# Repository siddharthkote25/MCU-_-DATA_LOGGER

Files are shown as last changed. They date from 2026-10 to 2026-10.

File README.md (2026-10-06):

# Mcu Data Logger

A compact, battery-backed data logger board built around the ATmega328P-AU. It has a real-time clock for timestamping and 2 Mbit of external I²C EEPROM for storage, and it breaks out I²C, UART, GPIO and ICSP headers for sensors and programming. Designed end-to-end in **KiCad 10**.

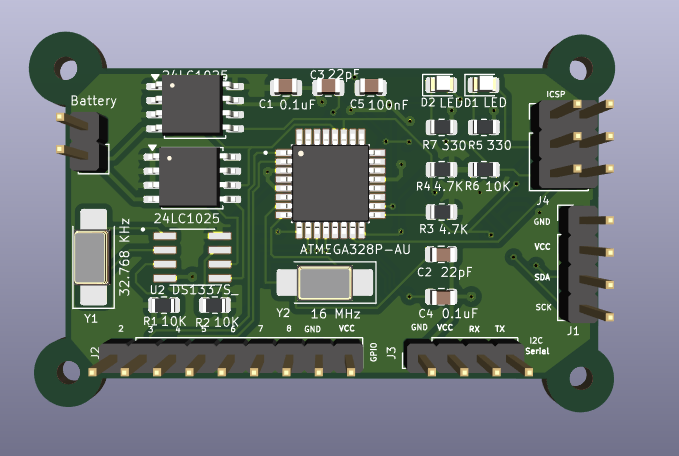
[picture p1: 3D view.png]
3D view


## Features

- **MCU:** ATmega328P-AU (TQFP-32) with a 16 MHz crystal and 22 pF load capacitors
- **Real-time clock:** DS1337 with a 32.768 kHz crystal, battery backup, and pull-ups on its SQW/INTA outputs
- **Storage:** 2 × 24LC1025 (1 Mbit each, 2 Mbit / 256 KB total) I²C EEPROMs, write-protect tied to GND
- **I²C bus:** 4.7 kΩ pull-ups on SDA/SCK, shared by the RTC and both EEPROMs
- **Indicators:** power LED and a status LED on SCK (D13)
- **Programming:** standard 2×3 ICSP header, with a 10 kΩ pull-up on RESET
- **Power:** battery input with decoupling on every IC, plus AREF filter capacitor
- **Mechanical:** four mounting holes, one in each corner

## Connectors

| Ref | Interface | Pins |
|-----|---|---|
| J1 | I²C | GND, VCC, SDA, SCK |
| J2 | GPIO | D2–D8, GND, VCC |
| J3 | Serial / UART | GND, VCC, RX, TX |
| J4 | ICSP | MISO, VCC, SCK, MOSI, RESET, GND |
| Battery | Power input | VCC, GND |

## Schematic

Hierarchical design, split into functional blocks:

- **MCU:** ATmega328P, crystal, reset circuit, LEDs, AREF filter
- **Real time clock:** DS1337, 32.768 kHz crystal, pull-ups, decoupling
- **EEPROM:** two 24LC1025 with address pins, write-protect and I²C pull-ups
- **Connectors:** I²C, UART, GPIO and ICSP (separate sub-sheet)
- **Mounting:** four mounting holes

**Sheet 1: MCU, RTC, EEPROM**

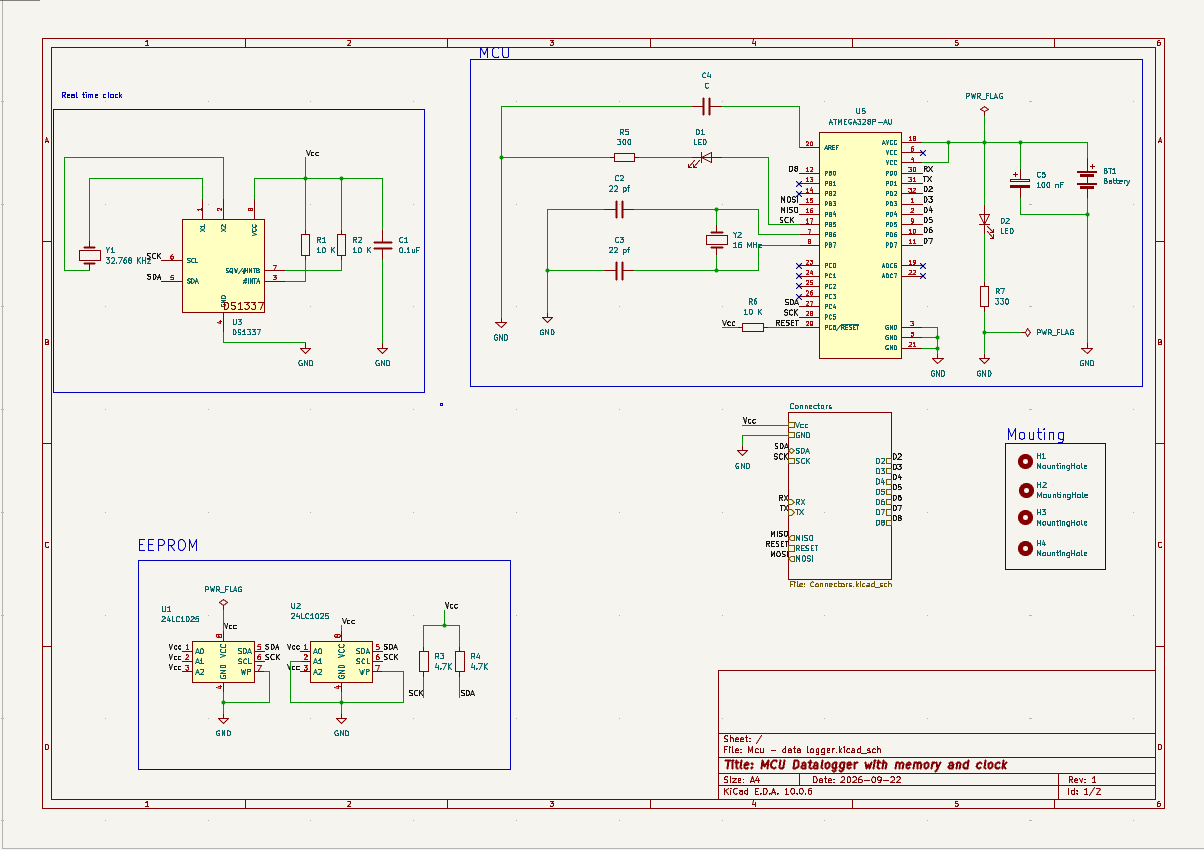
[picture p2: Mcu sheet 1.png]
Schematic sheet 1


**Sheet 2: Connectors**

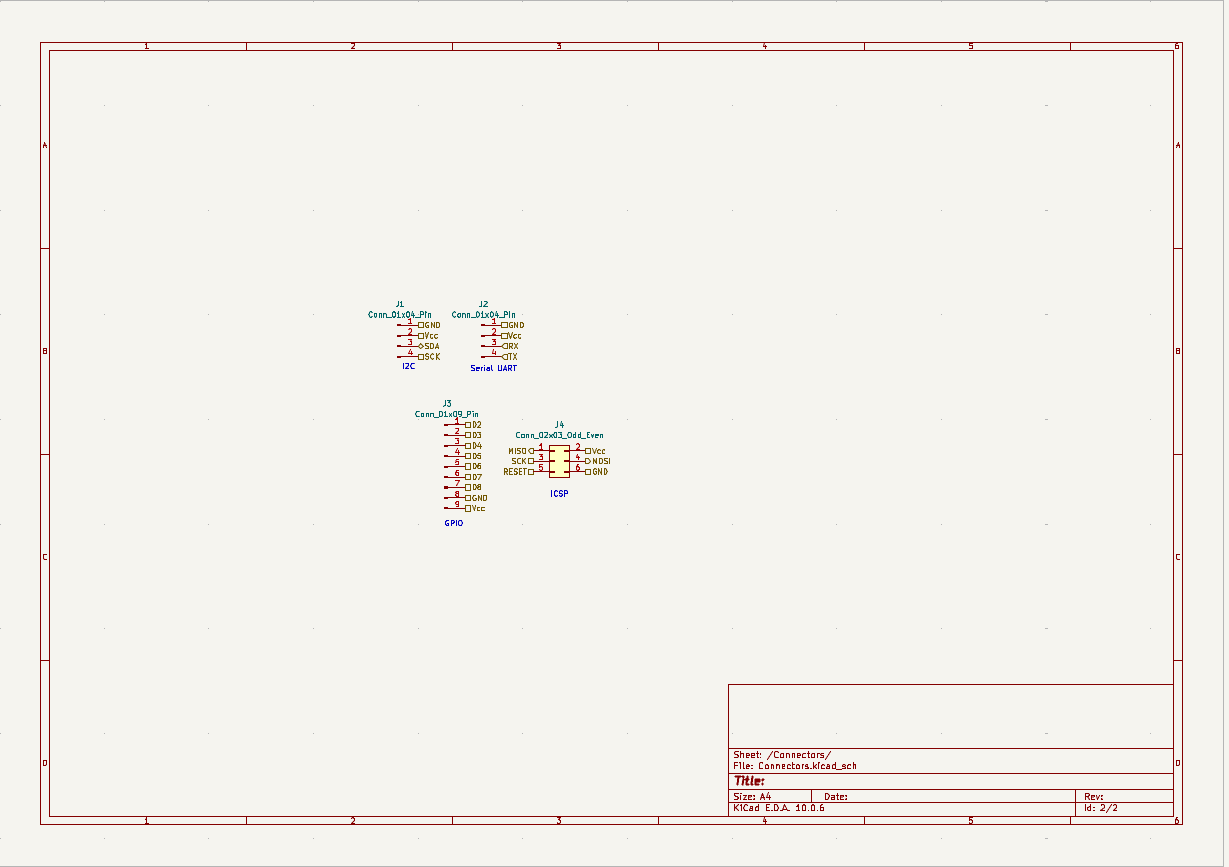
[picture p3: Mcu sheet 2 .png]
Schematic sheet 2


## PCB

- Layers: 2-layer
- Board size: [XX mm × XX mm]
- Components: mostly SMD (0603/0805 passives, TQFP-32, SOIC-8), through-hole headers
- Copper fills, silkscreen labelling for all connectors, DRC clean

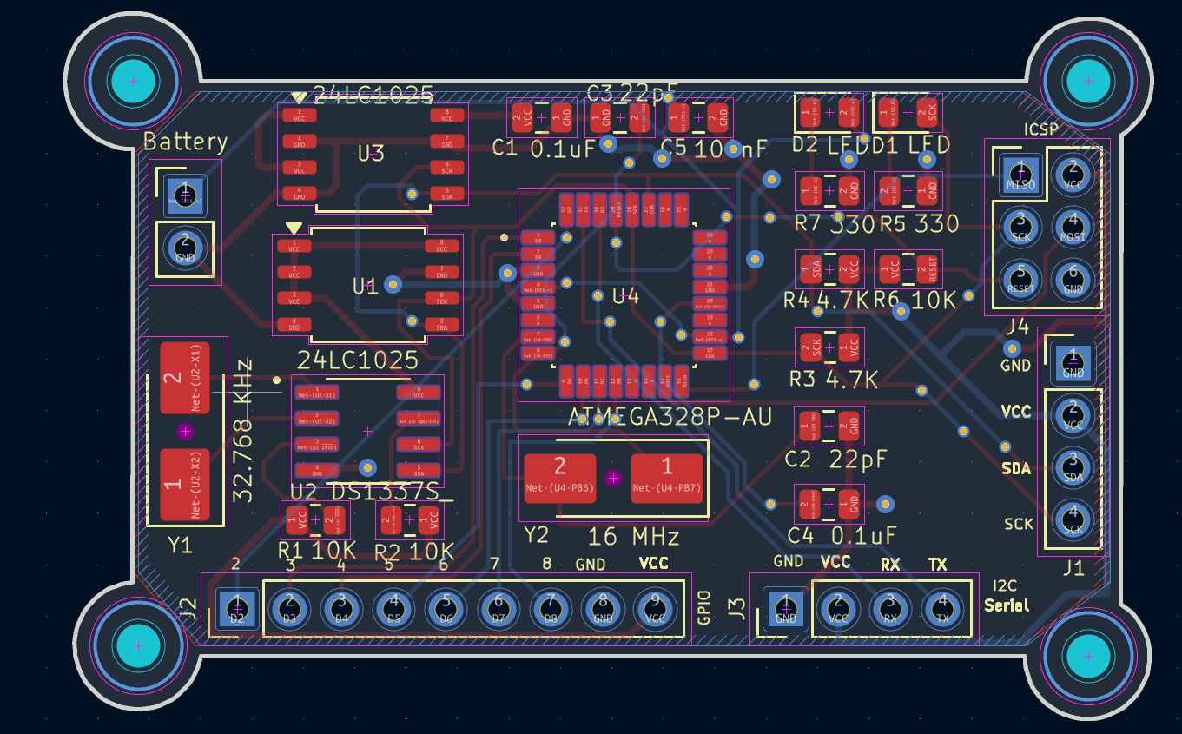
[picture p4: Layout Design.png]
PCB layout


## Repository Structure

```
.
├── ATMEGA328P-AU/               # MCU symbol / footprint / 3D model files
├── Footprints/                  # Custom footprint library
├── Gerbers/                     # Manufacturing outputs (Gerber + drill files)
├── symbols-downloaded/          # Downloaded symbol libraries
├── Mcu - data logger.kicad_pro  # KiCad project file
├── Mcu - data logger.kicad_sch  # Top-level schematic
├── Connectors.kicad_sch         # Connectors sub-sheet
├── Mcu - data logger.kicad_pcb  # PCB layout
├── sym-lib-table                # Project symbol library table
├── report.txt                   # Gerber/drill generation report
├── 3D view.png
├── Layout Design.png
├── Mcu sheet 1.png
├── Mcu sheet 2 .png
└── README.md
```

## Tools

- KiCad 10.0.6
- Git / GitHub for version control

## My details

**Siddharth Kote**
siddharthkote129@gmail.com

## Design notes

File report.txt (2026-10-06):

Info: X scale constrained.
Info: Y scale constrained.
Plotted to 'D:\MCU-_-DATA_LOGGER-main\Gerbers\Mcu - data logger-F_Cu.gbr'.
Plotted to 'D:\MCU-_-DATA_LOGGER-main\Gerbers\Mcu - data logger-B_Cu.gbr'.
Plotted to 'D:\MCU-_-DATA_LOGGER-main\Gerbers\Mcu - data logger-F_Paste.gbr'.
Plotted to 'D:\MCU-_-DATA_LOGGER-main\Gerbers\Mcu - data logger-B_Paste.gbr'.
Plotted to 'D:\MCU-_-DATA_LOGGER-main\Gerbers\Mcu - data logger-F_Silkscreen.gbr'.
Plotted to 'D:\MCU-_-DATA_LOGGER-main\Gerbers\Mcu - data logger-B_Silkscreen.gbr'.
Plotted to 'D:\MCU-_-DATA_LOGGER-main\Gerbers\Mcu - data logger-F_Mask.gbr'.
Plotted to 'D:\MCU-_-DATA_LOGGER-main\Gerbers\Mcu - data logger-B_Mask.gbr'.
Plotted to 'D:\MCU-_-DATA_LOGGER-main\Gerbers\Mcu - data logger-Edge_Cuts.gbr'.
Created Gerber job file 'D:\MCU-_-DATA_LOGGER-main\Gerbers\Mcu - data logger-job.gbrjob'.
Info: Done.

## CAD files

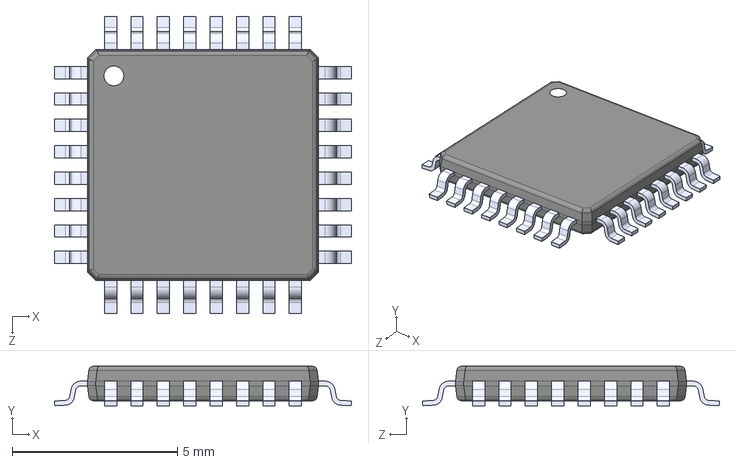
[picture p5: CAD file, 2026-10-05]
ATMEGA328P-AU/ATMEGA328P-AU.step
9.00 x 1.20 x 9.00 mm

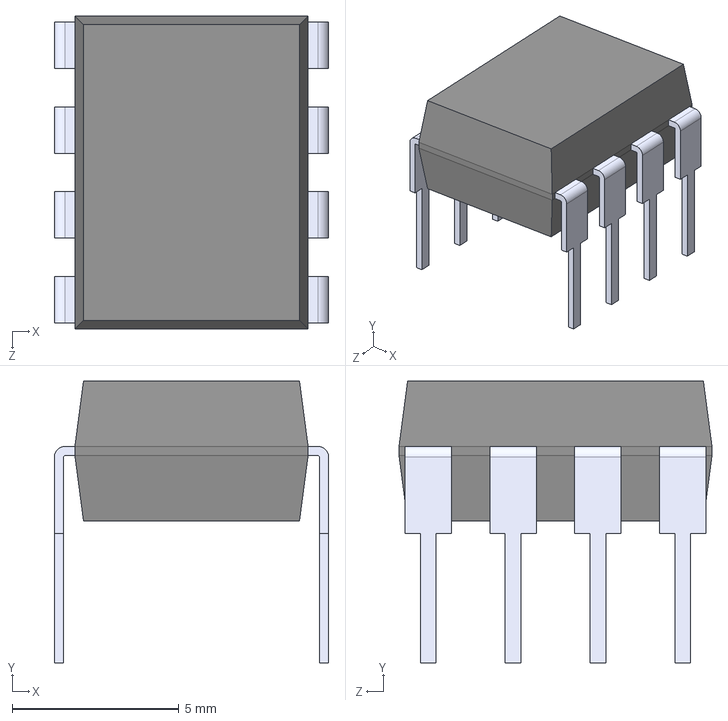
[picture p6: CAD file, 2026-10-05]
Footprints/DS1337/DS1337.step
8.22 x 8.44 x 9.38 mm

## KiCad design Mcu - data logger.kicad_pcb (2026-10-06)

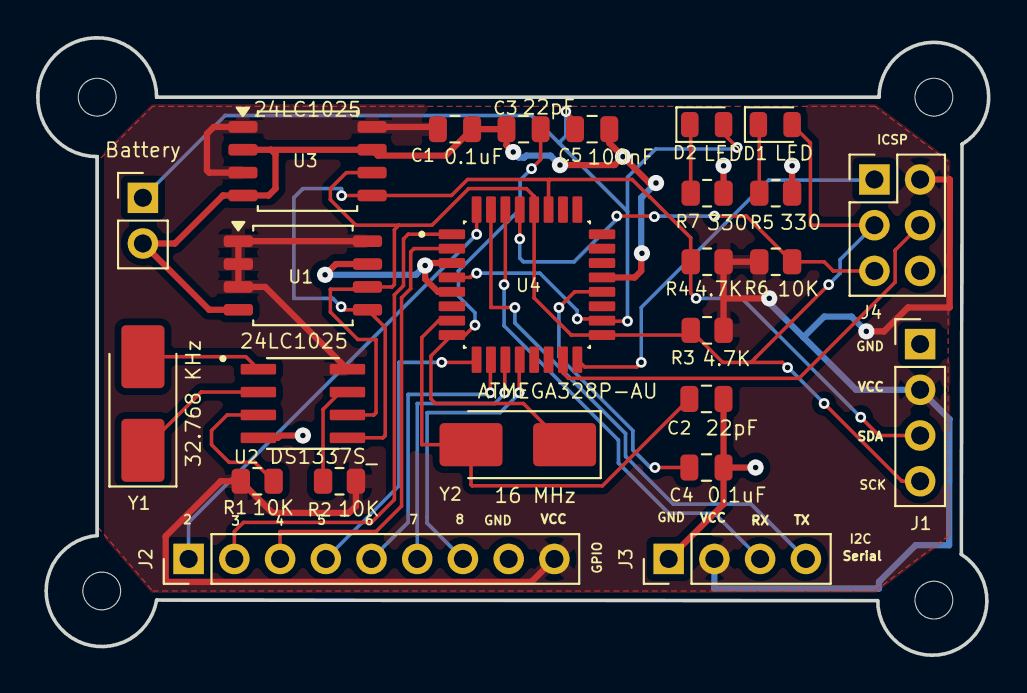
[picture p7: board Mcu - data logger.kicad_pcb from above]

Board: 2 copper layers, 52.8 x 34.3 mm, 29 parts (0 on the bottom side), 26 nets.

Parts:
BT1: Battery; PinHeader_1x02_P2.54mm_Vertical
C1, C4: 0.1uF; C_0805_2012Metric
C2, C3: 22pF; C_0805_2012Metric
C5: 100nF; C_0805_2012Metric
D1, D2: LED; LED_0805_2012Metric
H1, H2, H3, H4: MountingHole; MountingHole_2.1mm
J1, J3: Conn_01x04_Pin; PinHeader_1x04_P2.54mm_Vertical
J2: Conn_01x09_Pin; PinHeader_1x09_P2.54mm_Vertical
J4: Conn_02x03_Odd_Even; PinHeader_2x03_P2.54mm_Vertical
R1, R2, R6: 10K; R_0805_2012Metric
R3, R4: 4.7K; R_0805_2012Metric
R5, R7: 330; R_0805_2012Metric
U1, U3: 24LC1025; SOIC-8_5.3x5.3mm_P1.27mm
U2: DS1337S_; SOIC127P600X175-8N
U4: ATMEGA328P-AU; QFP80P900X900X120-32N
Y1: 32.768 KHz; Crystal_SMD_5032-2Pin_5.0x3.2mm_HandSoldering
Y2: 16 MHz; Crystal_SMD_5032-2Pin_5.0x3.2mm_HandSoldering

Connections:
/D2: J2.1, U4.32 (PD2)
/D3: J2.2, U4.1 (PD3)
/D4: J2.3, U4.2 (PD4)
/D5: J2.4, U4.9 (PD5)
/D6: J2.5, U4.10 (PD6)
/D7: J2.6, U4.11 (PD7)
/D8: J2.7, U4.12 (PB0)
/MISO: J4.1, U4.16 (PB4)
/MOSI: J4.4, U4.15 (PB3)
/RESET: J4.5, R6.2, U4.29 (PC6/~RESET)
/RX: J3.3, U4.30 (PD0)
/SCK: D1.2 (A), J1.4, J4.3, R3.2, U1.6 (SCL), U2.6 (SCL), U3.6 (SCL), U4.17 (PB5), U4.28 (PC5)
/SDA: J1.3, R4.1, U1.5 (SDA), U2.5 (SDA), U3.5 (SDA), U4.27 (PC4)
/TX: J3.4, U4.31 (PD1)
/VCC: C1.2, J1.2, J2.9, J3.2, J4.2, R1.1, R2.1, R3.1, R4.2, R6.1, U1.1 (A0), U1.2 (A1), U1.3 (A2), U1.8 (VCC), U2.8 (VCC), U3.1 (A0), U3.3 (A2), U3.8 (VCC)
GND: BT1.2 (-), C1.1, C2.2, C3.1, C4.1, C5.2, J1.1, J2.8, J3.1, J4.6, R5.1, R7.2, U1.4 (GND), U1.7 (WP), U2.4 (GND), U3.2 (A1), U3.4 (GND), U3.7 (WP), U4.3 (GND), U4.5 (GND), U4.21 (GND)
unnamed: BT1.1 (+), C5.1, D2.2 (A), U4.4 (VCC), U4.18 (AVCC)
unnamed: D1.1 (K), R5.2
unnamed: D2.1 (K), R7.1
unnamed: R2.2, U2.7 (SQW/~INT)
unnamed: U2.1 (X1), Y1.2
unnamed: U2.2 (X2), Y1.1
unnamed: R1.2, U2.3 (~INTA)
unnamed: C4.2, U4.20 (AREF)
unnamed: C2.1, U4.7 (PB6), Y2.2
unnamed: C3.2, U4.8 (PB7), Y2.1

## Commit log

2026-10-05 Routing done
    [ATMEGA328P-AU.step, Connectors.kicad_sch, DS1337.step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]
2026-10-06 Some more fixes
    [Mcu - data logger.kicad_pcb]
2026-10-06 Gerber files and characteristics
    [Mcu - data logger-B_Cu.gbr, Mcu - data logger-B_Mask.gbr, Mcu - data logger-B_Paste.gbr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]
2026-10-06 Layout design done
    [Mcu - data logger.kicad_pcb]
